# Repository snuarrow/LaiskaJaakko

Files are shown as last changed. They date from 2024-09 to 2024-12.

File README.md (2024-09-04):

# LaiskaJaakko

Development started on 07.06.2024, many things are still incomplete

Cheap Open Source WiFi Iot-sensor monitor platform

Features:
- Soil Moisture, Air Temperature & Humidity time series monitoring
- REST JSON endpoints for integrations
- Web user interface for stand-alone use
- React.js on Pi Pico W
- Configure WiFi via Pico hosted hotspot
- Cloud software-update from Git via Web-UI
- Time series graphs for each sensor in Web-UI
- Support for 3 plants per Pico for now

Features (work in progress):
- Remote server for remote use without virtual private networks

Requires following hardware (total cost ~9 euros / unit):
- Raspberry Pi Pico W
- AHT10 Temperature & humidity monitor
- 3x Analog 3.3v soil moisture sensor
- 3d-printed case

Build guide coming soon

Current simple UI:

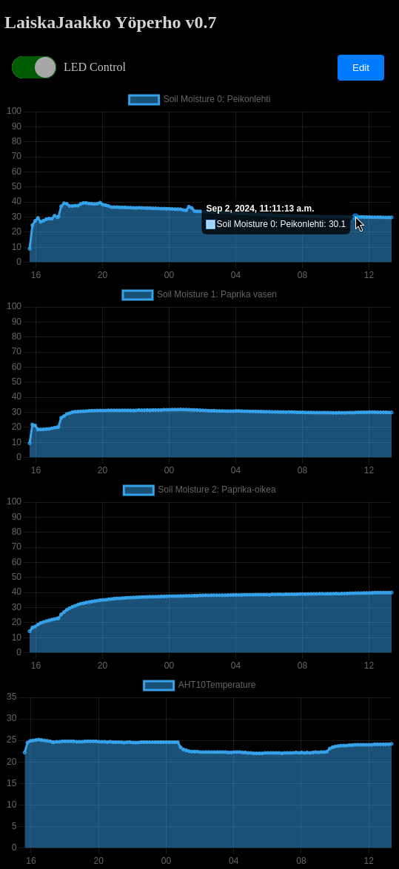
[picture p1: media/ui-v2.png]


Current version of unit assembled:

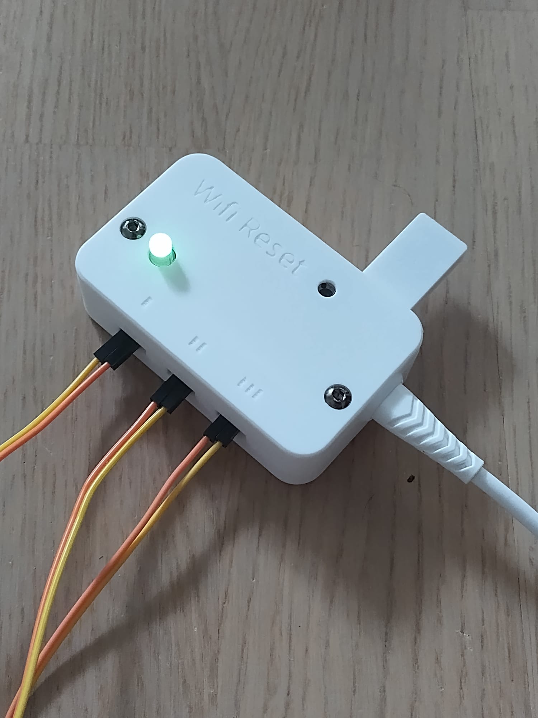
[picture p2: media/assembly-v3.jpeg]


User Manual (BETA RELEASE):
- When led is blinking blue the sensor is in AP-mode, then connect to hotspot: SSID: iot, pass: laiskajaakko, then navigate to 192.168.4.1 and set your own wifi credentials
- Led goes by default to disco mode if wifi connection is successful. It's solid red when there's no wifi connection
- Do some IT-wizardy and find out from which ip the sensor is found on your wifi subnet
- Open the ip with browser and enjoy
- One can delete configured WiFi credentials by pressing the WiFi Reset button for 5 seconds, then led should blink red and the sensor returns to blue blinking AP-mode

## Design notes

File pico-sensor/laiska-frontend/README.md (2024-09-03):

Raspberry Pi Pico W hosted React frontend for standalone use

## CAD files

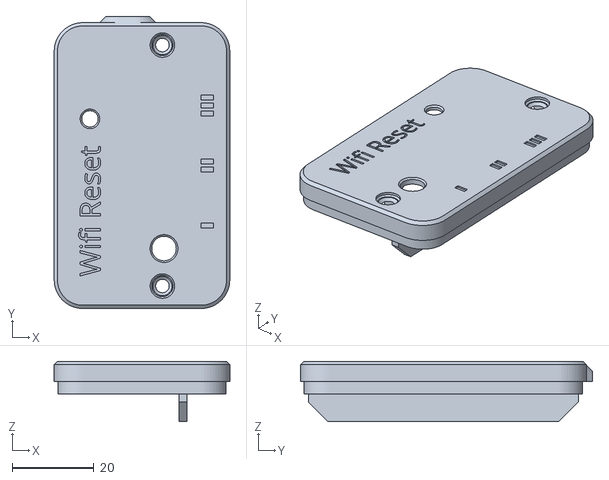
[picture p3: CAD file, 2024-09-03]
3D-models/LaiskaCase - Lid v1.4.stl
43.0 x 71.5 x 14.8

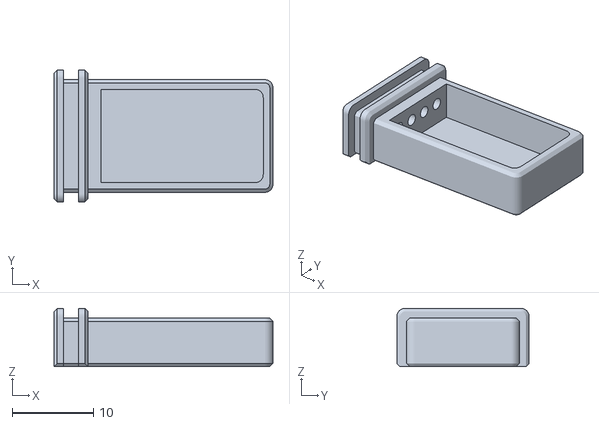
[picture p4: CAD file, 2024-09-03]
3D-models/AHT10Case v1.1.stl
27.0 x 16.3 x 7.20

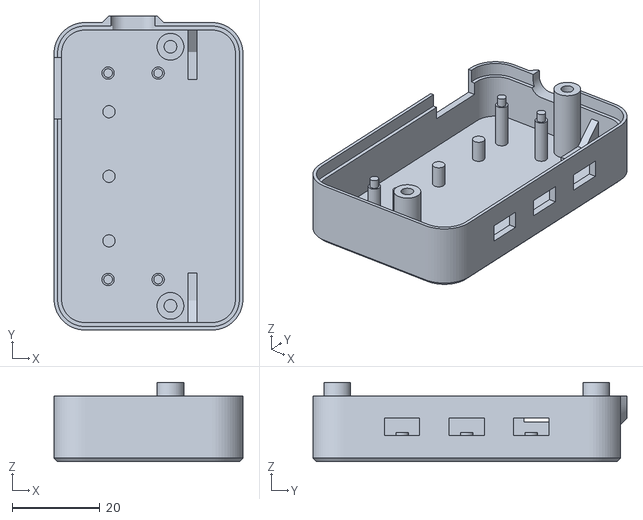
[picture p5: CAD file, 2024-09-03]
3D-models/LaiskaCase - Case v1.1.stl
43.0 x 71.5 x 18.1

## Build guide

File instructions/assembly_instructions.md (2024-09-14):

# Build Guide

### Required Components
Make sure you have all following hardware in hand before starting the assembly.
- Raspberry Pi Pico W
- AHT10 Temperature & Humidity sensor with I2C bus
- 3x Soil moisture sensor units
- 3x Soil moisture sensing forks
- Minimum of 30cm of single threaded Ø0,6mm equipment wire
- 6x 2-pin harwin connectors and corresponding female pins
- Enough flat-cable to do 3x 50cm pair cables
- A Biltema USB-cable (24-4011 or 24-4012 or 24-4013)
- 3D-printed case with all 3 parts (case, lid, aht10-case)
- 2x 5mm m3 machine screws
- Common cathode (common ground) 4-pin rgb led
- 2-pin tactile panel switch

### Required tools
- Soldering iron and tin
- Small and sharp side cutters
- Preferably a desoldering iron for removing the moisture sensor pins. With some soldering expertise one can cope without
- Bench press
- Preferably a pair of Harwin connector crimping pliers. With some expertise one can cope with regular multitool pliers or similar

### Preparation of wiring
From the equipement wire, cut following pieces:
- 4x 22mm
- 2x 38mm
- 1x 27mm
- 6x 20mm
Peel 1.5mm of insulation on all wires except the 20mm ones, they should be peeled completely.

### Preparation of other components
- De-solder the existing 4-pin connectors from the Soil-Moisture sensor units. Leave 2-pin connectors as they are.
- Make sure the screws fit the 3D-printed body by screwing them in couple of times with the lid on.
- Flash micropython into the Pico and make sure the Pico is not defective. (power on when pressing the bootsel button, then pico should appear as a storage device on Linux computer. Then copy the micropython firmware to Pico). Make sure you can i.e. blink the led on the Pico using micropython to assure that the board is working.

### Build Process
Follow the exact order of the build process, otherwise you might cause some difficulties for yourself
1. Using bench press, be gentle not to ruin the insulation of the wires. Solder 4x 22mm wires to the AHT10, wires should be pointing up from the component side of the pcb
2. Insert the soldered assembly into the printed AHT10 case
3. Solder the AHT assembly to Pico pins 1,2,3,4 from the bottom side of pico. The AHT10 component side should face inside of pico.
4. Make a tight bend to AHT wires so that both pico and AHT pcb's are paraller. Ensure proper fit with the 3D printed case.
5. Solder the 2-pin switch on the component side of Pico to pins 5, 7.
6. Cut excess wires of the switch.
7. Solder in the RGB-led to pins 21,22,23,24. Ground pin is the 23. Make sure that the led is properly positioned in-line with pins and the center of the led should be between pins 22 and 23. Try getting the LED close enough to the Pico pcb.
8. Cut excess wires of the led.
9. Ensure the fit to the case at this point
10. Solder 38mm, 27mm and 38mm wires for each of the moisture-sensors A0 pins. Wires should be facing the component side of the pcb
11. Solder 20mm completely stripped wires for all of the three moisture sensors. They should be in vcc and gnd pins.
12. For the moisture sensor 1 make a first bend paraller to the longest edge of the pcb. Second bend should be 90 degrees left after the potentiometer position. Third bend should be upwards just before the peeled end
13. For the moisture sensor 3 make exact same bending steps, but the turn to left should be right
14. For the moisture sensor 2, the first bend is the same as in the 1 and 3, but second at the position just after the potentiometer should face up
15. When positioning the 3 moisture sensors next to each other, the bended wires should line up next to each other
16. Cut all excess wires from all moisture sensors and try to make the back of the pcb's as flat as possible.
17. Insert moisture sensor 1 gnd and vcc wires to Pico pins 18,19. and leave unsoldered. Solder the A0 wire to Pico pin 31.
18. Insert moisture sensor 2 gnd and vcc wires to Pico pins 13,14. and leave unsoldered. Solder the A0 wire to Pico pin 32.
19. Insert moisture sensor 3 gnd and vcc wires to Pico pins 8,9. and leave unsoldered. Solder the A0 wire to Pico pin 34.
20. Slightly bending all the unsoldered wires, make the assembly fit nicely into the 3D-printed case. Be gentle.
21. Whilst the assembly is correctly in the case, solder the vcc and gnd wires of moisture sensors to pico.
22. Cut excess wires
23. Put the lid on with screws
24. Prepare 3 pair cables with the 2 pin female harwin connectors, they should be some 50cm in lenght or whatever you prefer. So far at least 70cm lenght has been tested to work. Longer might or might not cause issues, report such if you go crazy with the sensor wires.
24. Connect usb cable to pico and a Linux computer

### Flashing the software
1. Copy all necessary files to Pico root, one can use i.e. Thonny or similar:
- main.py
- typing.py
- version.json
- config.json
- ap_index.html
- components folder from pico-sensor folder
- dist folder from pico-sensor/laiska-frontend folder
2. Power cycle Pico and it should work

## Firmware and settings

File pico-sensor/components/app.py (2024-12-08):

from components.flasher import decide_action
from components.status_led import StatusLed

status_led = StatusLed()
decide_action(status_led=status_led)
from machine import Pin, reset, freq  # type: ignore
from components.wifi_reset_button import WifiResetButton
from components.network_connection import NetworkConnection
from components.web_real_time_clock import WebRealTimeClock
from components.cloud_updater import check_for_updates, download_update, get_download_status
from components.sensors import Sensors, save_config
from components.helpers import get_flash_sizes, CHUNK_SIZE, CONFIG_FILE
from components.microdot import Microdot, Response, Request
from time import sleep
from json import dumps, load
from typing import Tuple, Optional, Union
from gc import collect


frequency_MHz = 100
freq(frequency_MHz * 1000000)
pico_led = Pin("LED", Pin.OUT)
pico_led.value(0)
status_led.signal_power_on()
WifiResetButton(power_pin=5, signal_pin=3, status_led=status_led, pico_led=pico_led)
network_connection = NetworkConnection()
while True:
    if network_connection.ap_active():
        from components.ap_web_server import start_ap_web_server

        status_led.ap_mode_start()
        start_ap_web_server(status_led=status_led)
    if network_connection.wlan_active():
        status_led.disco_start()
        break
    sleep(5)
rtc = WebRealTimeClock()
sensors = Sensors(rtc=rtc)
app = Microdot()  # type: ignore


def internal_error(err: str) -> Tuple[str, int]:
    return dumps({
        "error": err
    }), 500


@app.route("/")  # type: ignore
def index(request: Request) -> Tuple[str, int, dict[str, str]]:
    with open("/dist/index.html") as f:
        return f.read(), 200, {"Content-Type": "text/html"}


@app.route("/api/v1/health", methods=["GET"])
def get_health(request: Request) -> Tuple[str, int]:
    return dumps({
        "ok": True
        # TODO: return also ram and disk usage
    }), 200


@app.route("/api/v1/sensor_meta", methods=["GET"])  # type: ignore
def get_meta(request: Request) -> Tuple[str, int]:
    with open(CONFIG_FILE, "r") as f:
        sensor_meta = load(f)["sensors"]
    return dumps(sensor_meta), 200


@app.route("/api/v1/sensor_data", methods=["GET"])  # type: ignore
def get_data(request: Request) -> Tuple[str, int]:
    sensor_index = int(request.args.get("sensor_index", 0))
    sensor_monitor = sensors.get_sensor(index=sensor_index)
    try:
        name = sensor_monitor.sensor.name  # type: ignore
    except:
        name = sensor_monitor.history.sensor_type
    sensor_data = sensor_monitor.get_data()
    sensor = sensor_monitor.get_sensor()
    values = []
    times = []
    for elem in sensor_data:
        if elem[1] < 1282542159:
            continue
        try:
            values.append(elem[0])
            times.append(elem[1])
        except:
            pass

    min, max = sensor.limits()
    response_data = {
        "index": sensor_index,
        "name": name,
        "type": sensor_monitor.history.sensor_type,
        "times": times,
        "values": values,
        "min": min,
        "max": max,
    }
    return dumps(response_data), 200


@app.route("/api/v1/sensor_name", methods=["POST"])  # type: ignore
def set_meta(request: Request) -> Tuple[str, int]:
    # changes the sensor given name based on query param sensor_index and json payload "given_name": "new_name"
    sensor_index = int(request.args.get("sensor_index", 0))
    data = request.json
    given_name = data.get("newName")
    with open(CONFIG_FILE, "r") as f:
        config = load(f)
        config["sensors"][sensor_index]["name"] = given_name
    save_config(updated_config=config)
    sensor_monitor = sensors.get_sensor(index=sensor_index)
    sensor_monitor.sensor.name = given_name  # type: ignore
    return dumps({"name": given_name}), 200


@app.route("/api/v1/led", methods=["GET"])  # type: ignore
def get_led(request: Request) -> Tuple[str, int]:
    return dumps({"value": int(status_led.lit)}), 200


@app.route("/api/v1/led", methods=["POST"])  # type: ignore
def set_led(request: Request) -> Tuple[str, int]:
    data = request.json
    value = data.get("value")
    if value == 0:
        status_led.disco_stop()
    elif value == 1:
        status_led.disco_start()
    return dumps({"led": status_led.lit}), 200


@app.route("/api/v1/updates_available", methods=["GET"])  # type: ignore
def get_updates_availalbe(request: Request) -> Tuple[str, int]:
    current_version, remote_version, updates_available, err = check_for_updates()
    if err:
        return internal_error(err=err)
    return (
        dumps(
            {
                "currentVersion": current_version,
                "remoteVersion": remote_version,
                "updatesAvailable": updates_available,
            }
        ),
        200,
    )


@app.route("/api/v1/reset", methods=["POST"])
def post_reset(request: Request):
    from machine import Timer
    def reset_wrapper(timer: Timer = None):
        # Wrapper is needed when reset is triggered with Timer
        reset()

    Timer().init(mode=Timer.ONE_SHOT, period=1000, callback=reset_wrapper)
    return dumps({"status": "resetting"}), 200


@app.route("/api/v1/download_firmware", methods=["POST"])  # type: ignore
def post_update_firmware(request: Request) -> Tuple[str, int]:
    force_update = request.args.get("force", 0)
    _, _, updates_available, err = check_for_updates()
    if err:
        return dumps({"error": err}), 500
    if updates_available or force_update:
        err = download_update()
        if err:
            return internal_error(err=err)
        err = get_download_status()
        if err:
            return internal_error(err=err)
        return dumps({
            "ready": True
        }), 200
    return dumps({"error": "no updates available"}), 400


@app.route("/<path:path>")  # type: ignore
def static(request: Request, path: str) -> Optional[Union[Tuple[str, int], Response]]:
    if "api/v1" in request.url:
        return None
    accept_encoding = request.headers.get("Accept-Encoding", "")
    path = f"/dist/{path}"
    if path.endswith(".js"):
        if "gzip" in accept_encoding:
            return serve_file(f"{path}.gz", "application/javascript", "gzip")
        else:
            return dumps({"error": "gzip not supported on browser"}), 400
    elif path.endswith(".css"):
        return serve_file(f"{path}.gz", "text/css", "gzip")
    elif path.endswith(".html"):
        return serve_file(path, "text/html")
    elif path.endswith(".ico"):
        return serve_file(path, "image/x-icon")
    return serve_file(path, "application/octet-stream")


def serve_file(file_path: str, content_type: str, encoding: str = "") -> Response:
    def file_stream():  # type: ignore
        try:
            with open(file_path, "rb") as f:
                while True:
                    chunk = f.read(CHUNK_SIZE)
                    if not chunk:
                        break
                    yield chunk
        except OSError as e:
            print(f"File not found: {file_path}")
            raise e

    headers = {"Content-Type": content_type}
    if encoding:
        headers["Content-Encoding"] = encoding
    return Response(body=file_stream(), headers=headers)  # type: ignore


print("all set")
try:
    app.run(host="0.0.0.0", port=80)  # type: ignore
except Exception as e:
    print("Exception in app.run", e)
    raise e

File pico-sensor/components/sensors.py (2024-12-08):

from components.web_real_time_clock import WebRealTimeClock
from typing import Tuple, Any, Optional
from os import remove, rename, listdir, mkdir
from machine import Timer, Pin, ADC, I2C  # type: ignore
from json import load, dump
from uos import urandom  # type: ignore
from ubinascii import hexlify  # type: ignore
from time import sleep
from gc import collect

HISTORY_LENGTH = 168
SAMPLING_FREQUENCY_SECONDS = 1800
CONFIG_FILE = "config.json"

def save_config(updated_config: dict[str, Any]) -> None:  # TODO: relocate
    with open(CONFIG_FILE, "w") as f:
        dump(updated_config, f)

def generate_uuid() -> str:
    random_bytes = urandom(16)
    uuid = hexlify(random_bytes).decode()
    return f"{uuid[:8]}-{uuid[8:12]}-{uuid[12:16]}-{uuid[16:20]}-{uuid[20:]}"

class Sensor:
    def __init__(self) -> None:
        pass

    def data_interface(self) -> float:
        return 0.0
    
    def limits(self) -> Tuple[int, int]:
        return 0, 100

class MoistureSensor(Sensor):
    def __init__(
        self,
        power_pin: int,
        adc_pin: int,
        voltage_0_percent: float,
        voltage_100_percent: float,
        name: str,
        uuid: str,
    ):
        self.adc_power_pin = Pin(power_pin, Pin.OUT)
        self.adc = ADC(Pin(adc_pin))
        self.voltage_0_percent = voltage_0_percent
        self.voltage_100_percent = voltage_100_percent
        self.name = name
        self.uuid = uuid

    def data_interface(self) -> float:
        return float(self.percentage())

    def voltage(self) -> float:
        self.adc_power_pin.value(1)
        sleep(0.01)
        adc_value = self.adc.read_u16()
        self.adc_power_pin.value(0)
        voltage = float(adc_value * 3.3 / 65535)
        return voltage

    def percentage(self) -> float:
        voltage = self.voltage()
        percentage = round(
            (
                1
                - (
                    (voltage - self.voltage_0_percent)
                    / (self.voltage_100_percent - self.voltage_0_percent)
                )
            )
            * 100,
            1
        )
        return percentage
    
    def limits(self) -> Tuple[int, int]:
        return 0, 100


class AHT10:
    def __init__(self, i2c_address: str, i2c_bus: int, i2c_sda_pin: int, i2c_scl_pin: int, power_pin: int) -> None:
        self.i2c_address = i2c_address
        self.power_pin = Pin(power_pin, Pin.OUT)
        self.power_pin.value(1)  # power on AHT10
        sleep(0.1)  # waith for AHT10 power up
        self.i2c = I2C(i2c_bus, scl=Pin(i2c_scl_pin), sda=Pin(i2c_sda_pin), freq=100000)
        self.init_sensor()

    def init_sensor(self) -> None:
        for i in range(10):
            try:
                self.i2c.writeto(int(self.i2c_address), b"\xE1\x08\x00")
                sleep(0.1)
                break
            except OSError as e:
                if i < 9:
                    continue
                raise e

    def _read_data(self) -> bytes:
        for i in range(10):
            try:
                self.i2c.writeto(int(self.i2c_address), b"\xAC\x33\x00")
                sleep(0.1)
                data: bytes = self.i2c.readfrom(int(self.i2c_address), 6)
                sleep(0.1)
                return data
            except OSError as e:
                if i < 9:
                    continue
                raise e
        raise Exception("AHT10 read failed")

    def get_temperature_and_humidity(self) -> Tuple[float, float]:
        data = self._read_data()
        humidity_int: int = ((data[1] << 16) | (data[2] << 8) | data[3]) >> 4
        temperature_int: int = ((data[3] & 0x0F) << 16) | (data[4] << 8) | data[5]

        humidity: float = (humidity_int * 100) / 1048576
        temperature: float = ((temperature_int * 200) / 1048576) - 53

        return temperature, humidity

    def get_temperature(self) -> float:
        data = self._read_data()
        temperature_int: int = ((data[3] & 0x0F) << 16) | (data[4] << 8) | data[5]
        temperature: float = ((temperature_int * 200) / 1048576) - 53
        return temperature

    def get_humidity(self) -> float:
        data = self._read_data()
        humidity_int: int = ((data[1] << 16) | (data[2] << 8) | data[3]) >> 4
        humidity: float = (humidity_int * 100) / 1048576
        return humidity


class AHT10TemperatureSensor(Sensor):
    def __init__(self, aht10: AHT10) -> None:
        self.aht10 = aht10

    def data_interface(self) -> float:
        return round(self.read_temperature(), 1)

    def read_temperature(self) -> float:
        return self.aht10.get_temperature()
    
    def limits(self) -> Tuple[int, int]:
        return 0, 100


class AHT10HumiditySensor(Sensor):
    def __init__(self, aht10: AHT10):
        self.aht10 = aht10

    def data_interface(self) -> float:
        return round(self.read_humidity(), 1)

    def read_humidity(self) -> float:
        return self.aht10.get_humidity()
    
    def limits(self) -> Tuple[int, int]:
        return 0, 100


class PicoTemperatureSensor(Sensor):
    conversion_factor = 3.3 / (65535)
    temperature_sensor = ADC(4)

    def data_interface(self) -> float:
        return round(self.read_temperature(), 1)

    def read_temperature(self) -> float:
        raw_value = self.temperature_sensor.read_u16()
        voltage = raw_value * self.conversion_factor
        temperature_c = float(27 - (voltage - 0.706) / 0.001721)
        return temperature_c

    def limits(self) -> Tuple[int, int]:
        return 0, 100
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

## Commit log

2024-07-10 better wifi connectivity & ability to find other sensors from same subnet
2024-08-12 dynamic sensor config
2024-08-12 dynamic sensor config & timestamps
2024-08-12 wifi reset button enabled
2024-08-22 better led control toggle (#24)
2024-08-25 UI improvements & bug fixes
    [ap_web_server.py, cloud_updater.py, helpers.py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]
2024-09-03 update pico frontend README.md
2024-09-03 Printable 3d-models
    [AHT10Case v1.1.stl, LaiskaCase - Case v1.1.stl, LaiskaCase - Lid v1.4.stl]
2024-09-04 fixed errors in type hints
    [ap_web_server.py, cloud_updater.py, helpers.py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]
2024-09-09 tests for POST /sensor_data endpoint
2024-09-14 assembly instructions
2024-12-08 UI firmware update & pico memory management
2024-12-08 load_json & error handling
    [app.py, cloud_updater.py, helpers.py]
2024-12-08 fix frontend update behaviour
    [app.py, cloud_updater.py, flasher.py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]
